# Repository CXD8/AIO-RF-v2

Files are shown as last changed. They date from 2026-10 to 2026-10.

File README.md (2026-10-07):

# AIO-RF-v2
An all-in-one RF platform built around the ESP32 C5, combining 2.4ghz + 5ghz Wi-Fi, Bluetooth, and sub-GHz RF into a single battery-powered device with a 2.8" LCD display and USB Type-C charging and battery integration.  

Connect via USB Type-C to flash firmware via your preferred flashing software through the USBC port, or choose to flash directly through the exposed tx and rx pins (before jumping connection to the modules. The MCP73871 handles battery charging path. Warning that the onboard battery controller does not have a cut-off threshold, a protected battery must be used. Refer to charging controller MCP73871-2CCI/ML for appropriate battery specifications. A battery is not required, it can be powered directly through USB-C.  

**Why**  
This device consolidates many features and a wide range of protocols and frequencies into one clean, portable device for wireless experimentation and IoT development.  
PCB  
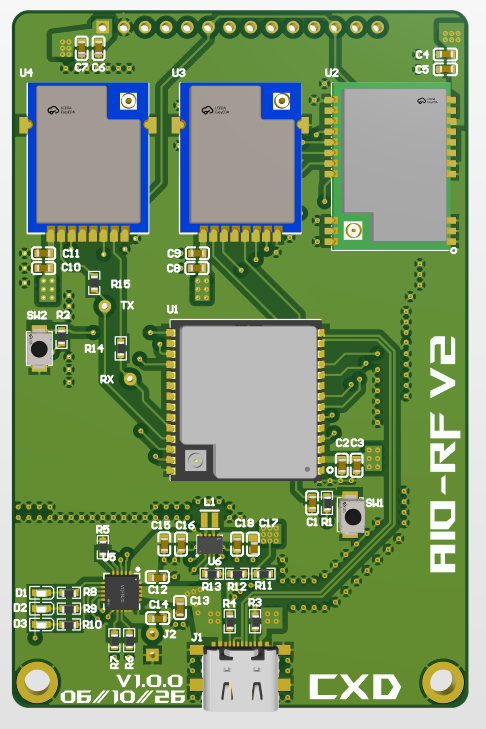
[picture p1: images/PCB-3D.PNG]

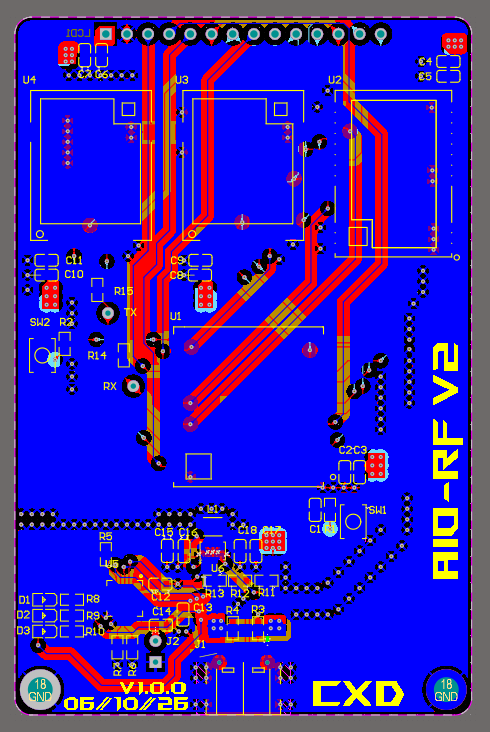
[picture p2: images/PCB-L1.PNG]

Schematic  
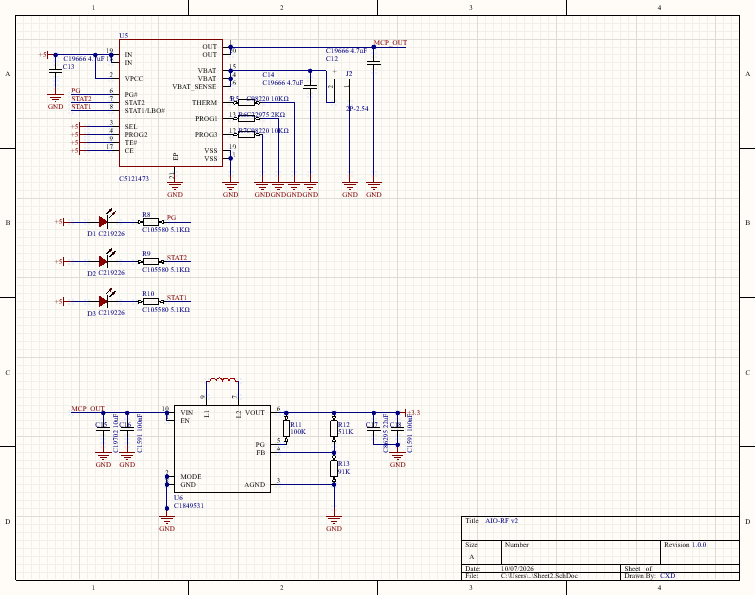
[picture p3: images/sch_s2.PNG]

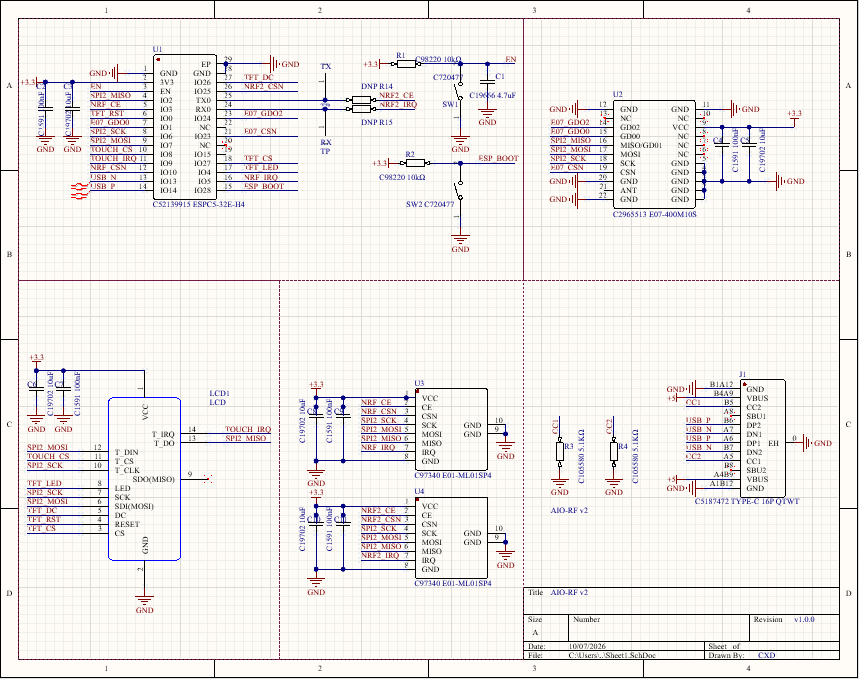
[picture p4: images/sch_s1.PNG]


Housing  
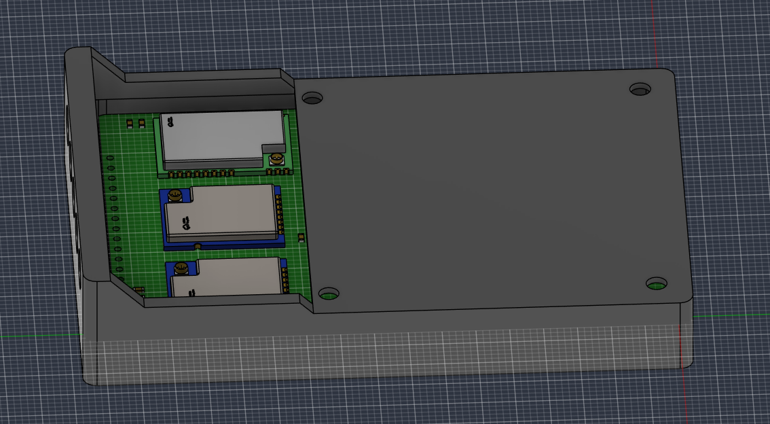
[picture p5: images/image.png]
Housing

  
**Bill of Materials**  
| Value | Description | Designator | Quantity | Part # | Purchase Link |
| :--- | :--- | :--- | :--- | :--- | :--- |
| 100nF | 100nF (104) ±10% 50V | C2, C4, C7,... | 5 | C1591 | https://www.lcsc.com/product-detail/C1591.html |
| 4.7uF | 4.7uF (475) ±10% 16V | C1 | 1 | C19666 | https://www.lcsc.com/product-detail/C19666.html |
| 10uF | 10uF (106) | C3, C5, C6,... | 5 | C19702 | https://www.lcsc.com/product-detail/C19702.html |
| E01-ML01SP4 | 2.4GHz Wireless Module | U3, U4 | 2 | C97340 | https://www.lcsc.com/product-detail/C97340.html |
| 10kΩ | Resistor 10kΩ | R1, R2 | 2 | C98220 | https://www.lcsc.com/product-detail/C98220.html |
| 5.1kΩ | Resistor 5.1kΩ | R3, R4 | 2 | C105580 | https://www.lcsc.com/product-detail/C105580.html |
| TS-1088-AR02016 | Tactile Switch SPST | SW1, SW2 | 2 | C720477 | https://www.lcsc.com/product-detail/C720477.html |
| E07-400M10S | CC1101 Wireless Module | U2 | 1 | C2965513 | https://www.lcsc.com/product-detail/C2965513.html |
| TYPE-C 16P QTWT | USB Type-C 16-Pin Receptacle | J1 | 1 | C5187472 | https://www.lcsc.com/product-detail/C5187472.html |
| ESPC5-32E-H4 | ESP32-C5 Wireless Module | U1 | 1 | C52139915 | https://www.lcsc.com/product-detail/C52139915.html |
| LCD | 2.8" SPI Touch Display | LCD1 | 1 | — | https://aliexpress.com/item/1005010008924503.html? |

**Changelog**

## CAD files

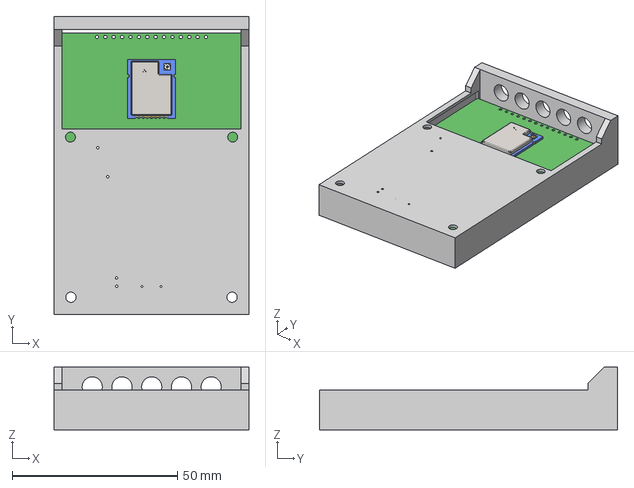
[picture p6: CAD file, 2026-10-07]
3d_models/AIO-RF-HOUSING.step
58.9 x 90.2 x 19.0 mm

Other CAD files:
3d_models/AIO-RF-HOUSING.f3d

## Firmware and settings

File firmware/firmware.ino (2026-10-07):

#include <Arduino.h>
#include <SPI.h>

// ============================================================
// ESPC5-32E custom board pinout
// ============================================================

// Shared SPI bus
static const int PIN_SPI_SCK  = 6;
static const int PIN_SPI_MOSI = 7;
static const int PIN_SPI_MISO = 2;

// ILI9488
static const int PIN_TFT_RST = 0;
static const int PIN_TFT_CS  = 27;
static const int PIN_TFT_DC  = 26;
static const int PIN_TFT_BL  = 4;

// XPT2046
static const int PIN_TOUCH_CS  = 8;
static const int PIN_TOUCH_IRQ = 9;

// NRF1
static const int PIN_NRF1_CE  = 3;
static const int PIN_NRF1_CSN = 10;
static const int PIN_NRF1_IRQ = 5;

// NRF2
// GPIO11/12 are also UART0 TX/RX. Keep your 0R links open for UART flashing.
static const int PIN_NRF2_CE  = 11;
static const int PIN_NRF2_IRQ = 12;
static const int PIN_NRF2_CSN = 25;

// E07-400M10S / CC1101
static const int PIN_E07_CSN  = 23;
static const int PIN_E07_GDO2 = 24;
static const int PIN_E07_GDO0 = 1;

// Boot
static const int PIN_BOOT = 28;

// GPIO15 deliberately unused for H16R8/PSRAM compatibility.

// ============================================================
// SPI settings
// ============================================================

SPISettings spiTFT(20000000, MSBFIRST, SPI_MODE0);
SPISettings spiTouch(2000000, MSBFIRST, SPI_MODE0);
SPISettings spiNRF(8000000, MSBFIRST, SPI_MODE0);
SPISettings spiCC1101(8000000, MSBFIRST, SPI_MODE0);

// ============================================================
// Analyzer settings
// ============================================================

enum AnalyzerMode : uint8_t {
  MODE_CC1101_433 = 0,
  MODE_NRF_24G    = 1
};

AnalyzerMode currentMode = MODE_CC1101_433;

static const int TFT_W = 320;
static const int TFT_H = 480;

static const int PLOT_TOP = 40;
static const int PLOT_BOTTOM = 400;
static const int PLOT_H = PLOT_BOTTOM - PLOT_TOP;

// CC1101 spectrum sweep.
// The E07-400M10S matching network is intended for the 433 MHz region.
static const int CC_BINS = 160;
static const float CC_SCAN_START_MHZ = 430.0f;
static const float CC_SCAN_STOP_MHZ  = 438.0f;
int16_t ccRssi[CC_BINS];
int16_t ccPeak[CC_BINS];

// nRF24L01 channel occupancy scan.
// RF_CH 0..125 corresponds to 2400..2525 MHz.
// RPD is NOT true RSSI: it only reports energy above roughly -64 dBm.
static const int NRF_CHANNELS = 126;
static const int NRF_SAMPLES_PER_CHANNEL = 8;
uint8_t nrfOccupancy[NRF_CHANNELS];
uint8_t nrfPeak[NRF_CHANNELS];

bool backlightOn = true;

// ============================================================
// Generic GPIO/SPI helpers
// ============================================================

static inline void allCSHigh()
{
  digitalWrite(PIN_TFT_CS, HIGH);
  digitalWrite(PIN_TOUCH_CS, HIGH);
  digitalWrite(PIN_NRF1_CSN, HIGH);
  digitalWrite(PIN_NRF2_CSN, HIGH);
  digitalWrite(PIN_E07_CSN, HIGH);
}

static inline int clampInt(int v, int lo, int hi)
{
  if (v < lo) return lo;
  if (v > hi) return hi;
  return v;
}

// ============================================================
// ILI9488 minimal driver, RGB666 / 18-bit pixel mode
// ============================================================

void tftWriteCommand(uint8_t cmd)
{
  SPI.beginTransaction(spiTFT);
  digitalWrite(PIN_TFT_CS, LOW);
  digitalWrite(PIN_TFT_DC, LOW);
  SPI.transfer(cmd);
  digitalWrite(PIN_TFT_CS, HIGH);
  SPI.endTransaction();
}

void tftWriteCommandData(uint8_t cmd, const uint8_t *data, size_t len)
{
  SPI.beginTransaction(spiTFT);
  digitalWrite(PIN_TFT_CS, LOW);

  digitalWrite(PIN_TFT_DC, LOW);
  SPI.transfer(cmd);

  digitalWrite(PIN_TFT_DC, HIGH);
  for (size_t i = 0; i < len; i++) SPI.transfer(data[i]);

  digitalWrite(PIN_TFT_CS, HIGH);
  SPI.endTransaction();
}

void ili9488Reset()
{
  digitalWrite(PIN_TFT_RST, HIGH);
  delay(10);
  digitalWrite(PIN_TFT_RST, LOW);
  delay(20);
  digitalWrite(PIN_TFT_RST, HIGH);
  delay(150);
}

void ili9488Init()
{
  ili9488Reset();

  const uint8_t gammaPos[] = {
    0x00,0x03,0x09,0x08,0x16,0x0A,0x3F,0x78,
    0x4C,0x09,0x0A,0x08,0x16,0x1A,0x0F
  };
  tftWriteCommandData(0xE0, gammaPos, sizeof(gammaPos));

  const uint8_t gammaNeg[] = {
    0x00,0x16,0x19,0x03,0x0F,0x05,0x32,0x45,
    0x46,0x04,0x0E,0x0D,0x35,0x37,0x0F
  };
  tftWriteCommandData(0xE1, gammaNeg, sizeof(gammaNeg));

  const uint8_t pwr1[] = {0x17,0x15};
  tftWriteCommandData(0xC0, pwr1, sizeof(pwr1));

  const uint8_t pwr2[] = {0x41};
  tftWriteCommandData(0xC1, pwr2, sizeof(pwr2));

  const uint8_t vcom[] = {0x00,0x12,0x80};
  tftWriteCommandData(0xC5, vcom, sizeof(vcom));

  const uint8_t madctl[] = {0x48};
  tftWriteCommandData(0x36, madctl, sizeof(madctl));

  // ILI9488 SPI pixel interface: 18-bit / RGB666
  const uint8_t pixfmt[] = {0x66};
  tftWriteCommandData(0x3A, pixfmt, sizeof(pixfmt));

  const uint8_t ifmode[] = {0x00};
  tftWriteCommandData(0xB0, ifmode, sizeof(ifmode));

  const uint8_t frctrl[] = {0xA0};
  tftWriteCommandData(0xB1, frctrl, sizeof(frctrl));

  const uint8_t invctrl[] = {0x02};
  tftWriteCommandData(0xB4, invctrl, sizeof(invctrl));

  const uint8_t dispfunc[] = {0x02,0x02};
  tftWriteCommandData(0xB6, dispfunc, sizeof(dispfunc));

  const uint8_t imgfunc[] = {0x00};
  tftWriteCommandData(0xE9, imgfunc, sizeof(imgfunc));

  const uint8_t adj3[] = {0xA9,0x51,0x2C,0x82};
  tftWriteCommandData(0xF7, adj3, sizeof(adj3));

  tftWriteCommand(0x11);
  delay(120);
  tftWriteCommand(0x29);
  delay(20);

  digitalWrite(PIN_TFT_BL, HIGH);
}

void ili9488SetAddrWindow(uint16_t x0, uint16_t y0, uint16_t x1, uint16_t y1)
{
  uint8_t d[4];

  d[0] = x0 >> 8; d[1] = x0;
  d[2] = x1 >> 8; d[3] = x1;
  tftWriteCommandData(0x2A, d, 4);

  d[0] = y0 >> 8; d[1] = y0;
  d[2] = y1 >> 8; d[3] = y1;
  tftWriteCommandData(0x2B, d, 4);

  tftWriteCommand(0x2C);
}

void ili9488FillRect(int x, int y, int w, int h, uint8_t r, uint8_t g, uint8_t b)
{
  if (w <= 0 || h <= 0) return;
  if (x < 0) { w += x; x = 0; }
  if (y < 0) { h += y; y = 0; }
  if (x + w > TFT_W) w = TFT_W - x;
  if (y + h > TFT_H) h = TFT_H - y;
  if (w <= 0 || h <= 0) return;

  ili9488SetAddrWindow(x, y, x + w - 1, y + h - 1);

  r &= 0xFC; g &= 0xFC; b &= 0xFC;

  SPI.beginTransaction(spiTFT);
  digitalWrite(PIN_TFT_CS, LOW);
  digitalWrite(PIN_TFT_DC, HIGH);

  uint32_t count = (uint32_t)w * (uint32_t)h;
  for (uint32_t i = 0; i < count; i++) {
    SPI.transfer(r);
    SPI.transfer(g);
    SPI.transfer(b);
  }

  digitalWrite(PIN_TFT_CS, HIGH);
  SPI.endTransaction();
}

void ili9488Clear(uint8_t r = 0, uint8_t g = 0, uint8_t b = 0)
{
  ili9488FillRect(0, 0, TFT_W, TFT_H, r, g, b);
}

void drawModeHeader()
{
  if (currentMode == MODE_CC1101_433) {
    // Orange/red header = 433 MHz analyzer
    ili9488FillRect(0, 0, TFT_W, 28, 220, 60, 0);
  } else {
    // Blue header = 2.4 GHz occupancy analyzer
    ili9488FillRect(0, 0, TFT_W, 28, 0, 80, 230);
  }

  // White separator
  ili9488FillRect(0, 28, TFT_W, 2, 255, 255, 255);
}

void drawPlotGrid()
{
  ili9488FillRect(0, PLOT_TOP, TFT_W, PLOT_H, 0, 0, 0);

  // Horizontal grey grid
  for (int y = PLOT_TOP; y <= PLOT_BOTTOM; y += PLOT_H / 5) {
    ili9488FillRect(0, y, TFT_W, 1, 48, 48, 48);
  }

  // Vertical grey grid
  for (int x = 0; x < TFT_W; x += TFT_W / 8) {
    ili9488FillRect(x, PLOT_TOP, 1, PLOT_H, 35, 35, 35);
  }
}

void showModeScreen()
{
  ili9488Clear();
  drawModeHeader();
  drawPlotGrid();

  // Bottom status strip:
  // left half = 433 mode touch hint, right half = 2.4 mode hint
  ili9488FillRect(0, 430, TFT_W / 2, 50, 90, 20, 0);
  ili9488FillRect(TFT_W / 2, 430, TFT_W / 2, 50, 0, 35, 100);
}

// ============================================================
// XPT2046
// ============================================================

uint16_t xpt2046Read12(uint8_t command)
{
  SPI.beginTransaction(spiTouch);
  digitalWrite(PIN_TOUCH_CS, LOW);

  SPI.transfer(command);
  uint16_t v = (uint16_t)SPI.transfer(0x00) << 8;
  v |= SPI.transfer(0x00);

  digitalWrite(PIN_TOUCH_CS, HIGH);
  SPI.endTransaction();

  return (v >> 3) & 0x0FFF;
}

void readTouchRaw(uint16_t &x, uint16_t &y)
{
  x = xpt2046Read12(0xD0);
  y = xpt2046Read12(0x90);
}

void handleTouchModeToggle()
{
  static bool wasDown = false;
  bool down = digitalRead(PIN_TOUCH_IRQ) == LOW;

  if (down && !wasDown) {
    currentMode = (currentMode == MODE_CC1101_433) ? MODE_NRF_24G : MODE_CC1101_433;
    Serial.printf("Mode -> %s\n",
      currentMode == MODE_CC1101_433 ? "CC1101 433 MHz spectrum" : "nRF 2.4 GHz occupancy");
    showModeScreen();
  }

  wasDown = down;
}

// ============================================================
// nRF24L01 low-level driver + 2.4 GHz occupancy analyzer
// ============================================================

static const uint8_t NRF_CMD_R_REGISTER = 0x00;
static const uint8_t NRF_CMD_W_REGISTER = 0x20;
static const uint8_t NRF_CMD_NOP        = 0xFF;

static const uint8_t NRF_REG_CONFIG   = 0x00;
static const uint8_t NRF_REG_EN_AA    = 0x01;
static const uint8_t NRF_REG_RF_CH    = 0x05;
static const uint8_t NRF_REG_RF_SETUP = 0x06;
static const uint8_t NRF_REG_STATUS   = 0x07;
static const uint8_t NRF_REG_RPD      = 0x09;

uint8_t nrfReadReg(int csn, uint8_t reg)
{
  SPI.beginTransaction(spiNRF);
  digitalWrite(csn, LOW);
  SPI.transfer(NRF_CMD_R_REGISTER | (reg & 0x1F));
  uint8_t v = SPI.transfer(NRF_CMD_NOP);
  digitalWrite(csn, HIGH);
  SPI.endTransaction();
  return v;
}

void nrfWriteReg(int csn, uint8_t reg, uint8_t value)
{
  SPI.beginTransaction(spiNRF);
  digitalWrite(csn, LOW);
  SPI.transfer(NRF_CMD_W_REGISTER | (reg & 0x1F));
  SPI.transfer(value);
  digitalWrite(csn, HIGH);
  SPI.endTransaction();
}

uint8_t nrfStatus(int csn)
{
  SPI.beginTransaction(spiNRF);
  digitalWrite(csn, LOW);
  uint8_t s = SPI.transfer(NRF_CMD_NOP);
  digitalWrite(csn, HIGH);
  SPI.endTransaction();
  return s;
}

void nrfInitScanner()
{
  digitalWrite(PIN_NRF1_CE, LOW);

  nrfWriteReg(PIN_NRF1_CSN, NRF_REG_EN_AA, 0x00);

  // 1 Mbps, 0 dBm transmit power setting.
  // TX is never enabled in analyzer mode; this just selects the RF data-rate mode.
  nrfWriteReg(PIN_NRF1_CSN, NRF_REG_RF_SETUP, 0x06);

  // PWR_UP=1, PRIM_RX=1
  nrfWriteReg(PIN_NRF1_CSN, NRF_REG_CONFIG, 0x03);

  delay(3);
}

uint8_t nrfMeasureChannelOccupancy(uint8_t channel)
{
  nrfWriteReg(PIN_NRF1_CSN, NRF_REG_RF_CH, channel);

  uint8_t hits = 0;

  for (int sample = 0; sample < NRF_SAMPLES_PER_CHANNEL; sample++) {
    // Enter RX long enough for the RPD detector to observe the channel.
    digitalWrite(PIN_NRF1_CE, HIGH);
    delayMicroseconds(180);

    if (nrfReadReg(PIN_NRF1_CSN, NRF_REG_RPD) & 0x01) hits++;

    digitalWrite(PIN_NRF1_CE, LOW);
    delayMicroseconds(40);
  }

  return (uint8_t)((hits * 100) / NRF_SAMPLES_PER_CHANNEL);
}

void scanNRF24()
{
  uint8_t bestChannel = 0;
  uint8_t bestOcc = 0;

  for (int ch = 0; ch < NRF_CHANNELS; ch++) {
    uint8_t occ = nrfMeasureChannelOccupancy((uint8_t)ch);
    nrfOccupancy[ch] = occ;
    if (occ > nrfPeak[ch]) nrfPeak[ch] = occ;

    if (occ > bestOcc) {
      bestOcc = occ;
      bestChannel = ch;
    }

    handleTouchModeToggle();
    if (currentMode != MODE_NRF_24G) return;
  }

  // Redraw plot
  ili9488FillRect(0, PLOT_TOP, TFT_W, PLOT_H, 0, 0, 0);

  const int barW = 2;
  const int graphW = NRF_CHANNELS * barW;
  const int x0 = (TFT_W - graphW) / 2;

  for (int ch = 0; ch < NRF_CHANNELS; ch++) {
    int h = (nrfOccupancy[ch] * (PLOT_H - 4)) / 100;
    int ph = (nrfPeak[ch] * (PLOT_H - 4)) / 100;
    int x = x0 + ch * barW;

    if (h > 0) {
      ili9488FillRect(x, PLOT_BOTTOM - h, barW, h, 0, 180, 255);
    }

    if (ph > 0) {
      ili9488FillRect(x, PLOT_BOTTOM - ph, barW, 2, 255, 255, 0);
    }
  }

  // Mark common Wi-Fi 2.4 GHz channel centers approximately:
  // Wi-Fi ch1=2412 -> NRF RF_CH=12, ch6=2437 -> 37, ch11=2462 -> 62.
  const uint8_t wifiCenters[] = {12, 37, 62};
  for (uint8_t i = 0; i < 3; i++) {
    int x = x0 + wifiCenters[i] * barW;
    ili9488FillRect(x, PLOT_TOP, 1, PLOT_H, 255, 80, 80);
  }

  Serial.printf("2.4G strongest: RF_CH=%u, %.0f MHz, occupancy=%u%%\n",
                bestChannel, 2400.0 + bestChannel, bestOcc);
}

// ============================================================
// CC1101 low-level driver + 433 MHz RSSI spectrum analyzer
// ============================================================

static const uint8_t CC_WRITE_BURST = 0x40;
static const uint8_t CC_READ_SINGLE = 0x80;
static const uint8_t CC_READ_BURST  = 0xC0;

// Configuration registers
static const uint8_t CC_IOCFG2   = 0x00;
static const uint8_t CC_IOCFG0   = 0x02;
static const uint8_t CC_PKTCTRL0 = 0x08;
static const uint8_t CC_FSCTRL1  = 0x0B;
static const uint8_t CC_FREQ2    = 0x0D;
static const uint8_t CC_FREQ1    = 0x0E;
static const uint8_t CC_FREQ0    = 0x0F;
static const uint8_t CC_MDMCFG4  = 0x10;
static const uint8_t CC_MDMCFG3  = 0x11;
static const uint8_t CC_MDMCFG2  = 0x12;
static const uint8_t CC_DEVIATN  = 0x15;
static const uint8_t CC_MCSM0    = 0x18;
static const uint8_t CC_FOCCFG   = 0x19;
static const uint8_t CC_AGCCTRL2 = 0x1B;
static const uint8_t CC_AGCCTRL1 = 0x1C;
static const uint8_t CC_AGCCTRL0 = 0x1D;
static const uint8_t CC_FREND1   = 0x21;
static const uint8_t CC_FREND0   = 0x22;
static const uint8_t CC_FSCAL3   = 0x23;
static const uint8_t CC_FSCAL2   = 0x24;
static const uint8_t CC_FSCAL1   = 0x25;
static const uint8_t CC_FSCAL0   = 0x26;
static const uint8_t CC_TEST2    = 0x2C;
static const uint8_t CC_TEST1    = 0x2D;
static const uint8_t CC_TEST0    = 0x2E;

// Status registers
static const uint8_t CC_PARTNUM = 0x30;
static const uint8_t CC_VERSION = 0x31;
static const uint8_t CC_RSSI    = 0x34;

// Command strobes
static const uint8_t CC_SRES  = 0x30;
static const uint8_t CC_SCAL  = 0x33;
static const uint8_t CC_SRX   = 0x34;
static const uint8_t CC_SIDLE = 0x36;
static const uint8_t CC_SNOP  = 0x3D;

bool ccWaitReady(uint32_t timeoutUs = 2500)
{
  uint32_t start = micros();
  while (digitalRead(PIN_SPI_MISO) == HIGH) {
    if ((micros() - start) > timeoutUs) return false;
  }
  return true;
}

uint8_t ccStrobe(uint8_t cmd)
{
  SPI.beginTransaction(spiCC1101);
  digitalWrite(PIN_E07_CSN, LOW);
  ccWaitReady();
  uint8_t status = SPI.transfer(cmd);
  digitalWrite(PIN_E07_CSN, HIGH);
  SPI.endTransaction();
  return status;
}

void ccWriteReg(uint8_t addr, uint8_t value)
{
  SPI.beginTransaction(spiCC1101);
  digitalWrite(PIN_E07_CSN, LOW);
  ccWaitReady();
  SPI.transfer(addr);
  SPI.transfer(value);
  digitalWrite(PIN_E07_CSN, HIGH);
  SPI.endTransaction();
}

uint8_t ccReadReg(uint8_t addr)
{
  SPI.beginTransaction(spiCC1101);
  digitalWrite(PIN_E07_CSN, LOW);
  ccWaitReady();
  SPI.transfer(addr | CC_READ_SINGLE);
  uint8_t v = SPI.transfer(0);
  digitalWrite(PIN_E07_CSN, HIGH);
  SPI.endTransaction();
  return v;
}

uint8_t ccReadStatusReg(uint8_t addr)
{
  // CC1101 status-register reads require both READ and BURST bits.
  SPI.beginTransaction(spiCC1101);
  digitalWrite(PIN_E07_CSN, LOW);
  ccWaitReady();
  SPI.transfer(addr | CC_READ_BURST);
  uint8_t v = SPI.transfer(0);
  digitalWrite(PIN_E07_CSN, HIGH);
  SPI.endTransaction();
  return v;
}

void ccReset()
{
  digitalWrite(PIN_E07_CSN, HIGH);
  delayMicroseconds(50);
  digitalWrite(PIN_E07_CSN, LOW);
  delayMicroseconds(10);
  digitalWrite(PIN_E07_CSN, HIGH);
  delayMicroseconds(50);

  ccStrobe(CC_SRES);
  delay(2);
}

void ccInitAnalyzer()
{
  ccReset();

  // Conservative 433 MHz receiver configuration.
  // Approx. 200 kHz RX bandwidth, 2-FSK receiver path.
  ccWriteReg(CC_IOCFG2,   0x29);
  ccWriteReg(CC_IOCFG0,   0x06);
  ccWriteReg(CC_PKTCTRL0, 0x32);
  ccWriteReg(CC_FSCTRL1,  0x06);
  ccWriteReg(CC_MDMCFG4,  0xCA);
  ccWriteReg(CC_MDMCFG3,  0x83);
  ccWriteReg(CC_MDMCFG2,  0x13);
  ccWriteReg(CC_DEVIATN,  0x35);
  ccWriteReg(CC_MCSM0,    0x18);
  ccWriteReg(CC_FOCCFG,   0x16);
  ccWriteReg(CC_AGCCTRL2, 0x43);
  ccWriteReg(CC_AGCCTRL1, 0x40);
  ccWriteReg(CC_AGCCTRL0, 0x91);
  ccWriteReg(CC_FREND1,   0x56);
  ccWriteReg(CC_FREND0,   0x10);
  ccWriteReg(CC_FSCAL3,   0xE9);
  ccWriteReg(CC_FSCAL2,   0x2A);
  ccWriteReg(CC_FSCAL1,   0x00);
  ccWriteReg(CC_FSCAL0,   0x1F);
  ccWriteReg(CC_TEST2,    0x81);
  ccWriteReg(CC_TEST1,    0x35);
  ccWriteReg(CC_TEST0,    0x09);

  ccStrobe(CC_SIDLE);
}

void ccSetFrequencyMHz(float mhz)
{
  // E07/CC1101 normally uses a 26 MHz crystal.
  const float FXOSC_MHZ = 26.0f;
  uint32_t word = (uint32_t)((mhz * 65536.0f / FXOSC_MHZ) + 0.5f);

  ccWriteReg(CC_FREQ2, (word >> 16) & 0xFF);
  ccWriteReg(CC_FREQ1, (word >> 8) & 0xFF);
  ccWriteReg(CC_FREQ0, word & 0xFF);
}

int16_t ccRssiDbm()
{
  uint8_t raw = ccReadStatusReg(CC_RSSI);
  int16_t signedRaw = (raw >= 128) ? ((int16_t)raw - 256) : raw;

  // Typical CC1101 RSSI offset near 433 MHz.
  // Treat this as an estimate, not calibrated lab-grade power.
  return (signedRaw / 2) - 74;
}

int16_t ccMeasureRssi(float mhz)
{
  ccStrobe(CC_SIDLE);
  ccSetFrequencyMHz(mhz);

  // Explicit calibration for each tune step: slower but robust for a demo analyzer.
  ccStrobe(CC_SCAL);
  delayMicroseconds(800);

  ccStrobe(CC_SRX);
  delayMicroseconds(1000);

  int32_t sum = 0;
  const int samples = 3;
  for (int i = 0; i < samples; i++) {
    sum += ccRssiDbm();
    delayMicroseconds(180);
  }

  ccStrobe(CC_SIDLE);
  return (int16_t)(sum / samples);
}

void scanCC1101()
{
  int16_t bestRssi = -127;
  int bestBin = 0;

  for (int i = 0; i < CC_BINS; i++) {
    float f = CC_SCAN_START_MHZ +
      (CC_SCAN_STOP_MHZ - CC_SCAN_START_MHZ) * ((float)i / (CC_BINS - 1));

    int16_t rssi = ccMeasureRssi(f);
    ccRssi[i] = rssi;

    if (rssi > ccPeak[i]) ccPeak[i] = rssi;

    if (rssi > bestRssi) {
      bestRssi = rssi;
      bestBin = i;
    }

    handleTouchModeToggle();
    if (currentMode != MODE_CC1101_433) return;
  }

  // Redraw graph area.
  ili9488FillRect(0, PLOT_TOP, TFT_W, PLOT_H, 0, 0, 0);

  const int barW = 2;

  for (int i = 0; i < CC_BINS; i++) {
    // Graph scale: -110 dBm floor to -30 dBm top.
    int rssi = clampInt(ccRssi[i], -110, -30);
    int peak = clampInt(ccPeak[i], -110, -30);

    int h = ((rssi + 110) * (PLOT_H - 4)) / 80;
    int ph = ((peak + 110) * (PLOT_H - 4)) / 80;
    int x = i * barW;

    if (h > 0) {
      ili9488FillRect(x, PLOT_BOTTOM - h, barW, h, 0, 220, 80);
    }

    if (ph > 0) {
      ili9488FillRect(x, PLOT_BOTTOM - ph, barW, 2, 255, 80, 40);
    }
  }

  float bestFreq = CC_SCAN_START_MHZ +
    (CC_SCAN_STOP_MHZ - CC_SCAN_START_MHZ) * ((float)bestBin / (CC_BINS - 1));

  Serial.printf("433 sweep peak: %.3f MHz, approx RSSI=%d dBm\n", bestFreq, bestRssi);
}

// ============================================================
// Diagnostics / controls
// ============================================================

void resetPeakHold()
{
  for (int i = 0; i < CC_BINS; i++) ccPeak[i] = -120;
  for (int i = 0; i < NRF_CHANNELS; i++) nrfPeak[i] = 0;
  Serial.println("Peak hold reset");
}

void printDiagnostics()
{
  uint8_t ccPart = ccReadStatusReg(CC_PARTNUM);
  uint8_t ccVer  = ccReadStatusReg(CC_VERSION);

  Serial.println();
  Serial.println("=== RF board diagnostics ===");
  Serial.printf("CC1101 PARTNUM: 0x%02X\n", ccPart);
  Serial.printf("CC1101 VERSION: 0x%02X\n", ccVer);
  Serial.printf("NRF1 STATUS:    0x%02X\n", nrfStatus(PIN_NRF1_CSN));
  Serial.printf("NRF1 CONFIG:    0x%02X\n", nrfReadReg(PIN_NRF1_CSN, NRF_REG_CONFIG));
  Serial.printf("NRF2 STATUS:    0x%02X\n", nrfStatus(PIN_NRF2_CSN));
  Serial.printf("BOOT:           %d\n", digitalRead(PIN_BOOT));
  Serial.printf("E07 GDO0/GDO2:  %d/%d\n",
                digitalRead(PIN_E07_GDO0), digitalRead(PIN_E07_GDO2));
  Serial.println("============================");
}

void handleSerialControls()
{
  while (Serial.available()) {
    char c = Serial.read();

    if (c == '1') {
      currentMode = MODE_CC1101_433;
      showModeScreen();
      Serial.println("Mode: 433 MHz CC1101 RSSI spectrum");
    }
    else if (c == '2') {
      currentMode = MODE_NRF_24G;
      showModeScreen();
      Serial.println("Mode: 2.4 GHz nRF RPD occupancy");
    }
    else if (c == 'r' || c == 'R') {
      resetPeakHold();
    }
    else if (c == 'd' || c == 'D') {
      printDiagnostics();
    }
    else if (c == 'b' || c == 'B') {
      backlightOn = !backlightOn;
      digitalWrite(PIN_TFT_BL, backlightOn ? HIGH : LOW);
    }
  }
}

// ============================================================
// Setup / loop
// ============================================================
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
void loop()
{
  handleSerialControls();
  handleTouchModeToggle();

  if (currentMode == MODE_CC1101_433) {
    scanCC1101();
  } else {
    scanNRF24();
  }
}
